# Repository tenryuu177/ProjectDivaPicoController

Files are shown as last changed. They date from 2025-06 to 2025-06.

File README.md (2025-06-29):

# Project Diva Controller

## Main features:
- Cheap (about 10€)
- Compact (fits 250x250 Print beds)
- 4 Main buttons
- Fake Slide pad using buttons
- Enter/Escape Keys

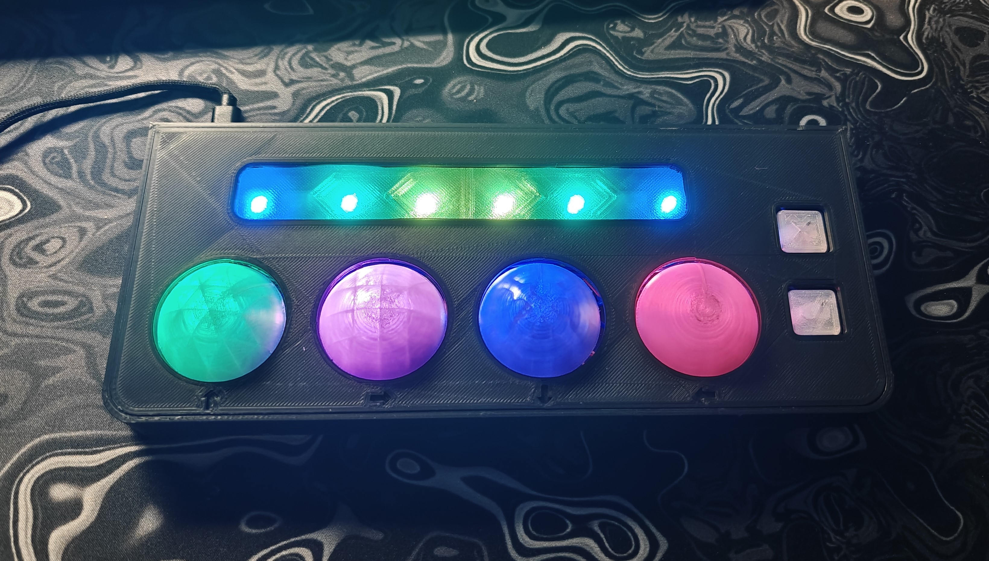
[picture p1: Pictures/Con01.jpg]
Con01


## What you need:
The links lead to AliExpress
- 1x [Raspberry Pi Pico (with USB-C)](https://www.aliexpress.com/item/1005008574488243.html?spm=a2g0o.order_list.order_list_main.5.2c061802aOrQjI)
- 8x [Kailh Choc switches](https://www.aliexpress.com/item/1005006626760418.html?spm=a2g0o.order_list.order_list_main.30.2c061802aOrQjI)
- 10x [WS2812B 5050SMD LEDs](https://www.aliexpress.com/item/4000750610574.html?spm=a2g0o.order_list.order_list_main.45.2c061802aOrQjI)
- super glue
- 3D Printer
- Clear Filament and any other color you might want
- Soldering Iron
- Wires
- Protoboard/Perfboard for easier wiring (optional but highly recommended)

# How to build:
Choose between the press fit and the M3 threaded version and print all parts.
The buttons don't require any (or only minimal) post-processing when printed with 0.1mm layers they are smooth enough as is.
Print the buttons with low infill so that they stay lightweight and more transparent. I choose to give them all different infill patterns similar to their symbol.

I used the following settings:

Triangle with 15% triangle infill, rotate 45° so that the pattern aligns.

Square with 10% grid infill pattern, rotate the part 45° so that the pattern aligns.

Circle with 10% concentric infill pattern.

Cross with 10% Cross pattern

'ChocStem' needs to be printed 4 times and they are going to be glued to the main buttons.

'ChocBody' needs to be printed 6 times and they are used for all the buttons.

'ChocBodyShort' needs to be printed 2 times and they are placed underneath the slidebar.

The ChocBody parts should have a pretty tight fit so that they can be pressed in place but still removed later if needed. Might need some sanding to get them in or you could just glue them in.

## Wiring
### Buttons
I choose the following GPIO Pins

Triangle/W GP16

Square/A GP17

Cross/S: GP18 

Circle/D: GP19 

Enter: GP20 

Escape: GP21 

Slide Left/Q: GP4 

Slide Right/E: GP5

However, you can wire these any way you want and then alter the assigned GPIO Pins starting from line 23 in the code.

### LEDs
The first 4 LEDs are Triangle, Square, Cross, and Circle in that order and light up along with button presses.

The last 6 LEDs should also be wired in series as in the picture, they have a RGB cycle and either side lights up respectively when pressed.

The Data In of the first LED has to be connected with GP0 after that, they are wired in series.
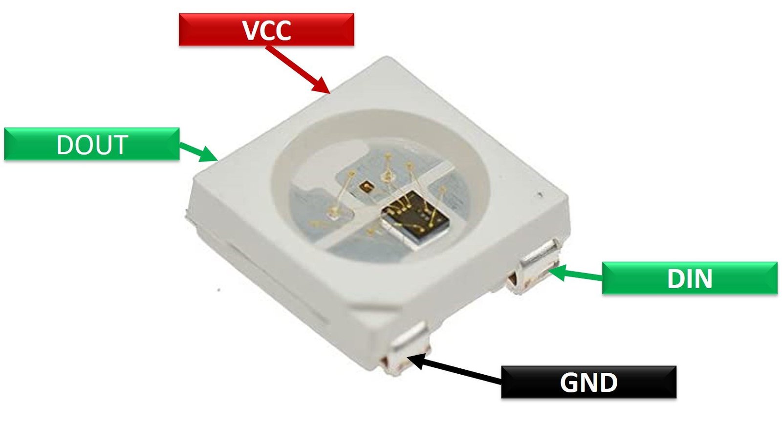
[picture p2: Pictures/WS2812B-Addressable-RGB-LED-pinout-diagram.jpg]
LED-Pinout

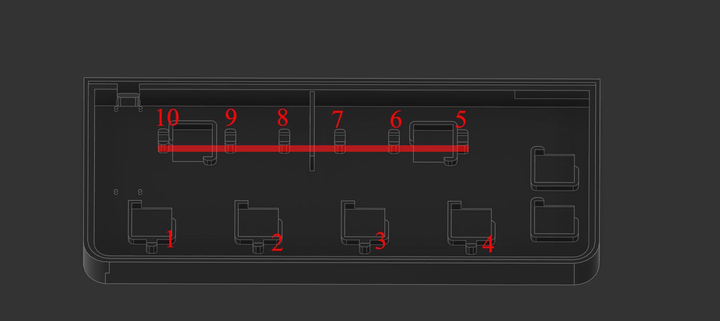
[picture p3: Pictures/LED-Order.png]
LED-Order


# Raspberry setup

First, flash your Raspberry with the latest Circuit Python version available: https://circuitpython.org/board/raspberry_pi_pico/

Then drop the content of the Raspberry folder onto your Raspberry.

The 'lib' folder and 'code.py' should be in root.

After disconnecting and reconnecting your Raspberry, the board should light up after a few seconds

# Disclaimer
The code was entirely written by Google Gemini.
I only changed some values for the LEDs

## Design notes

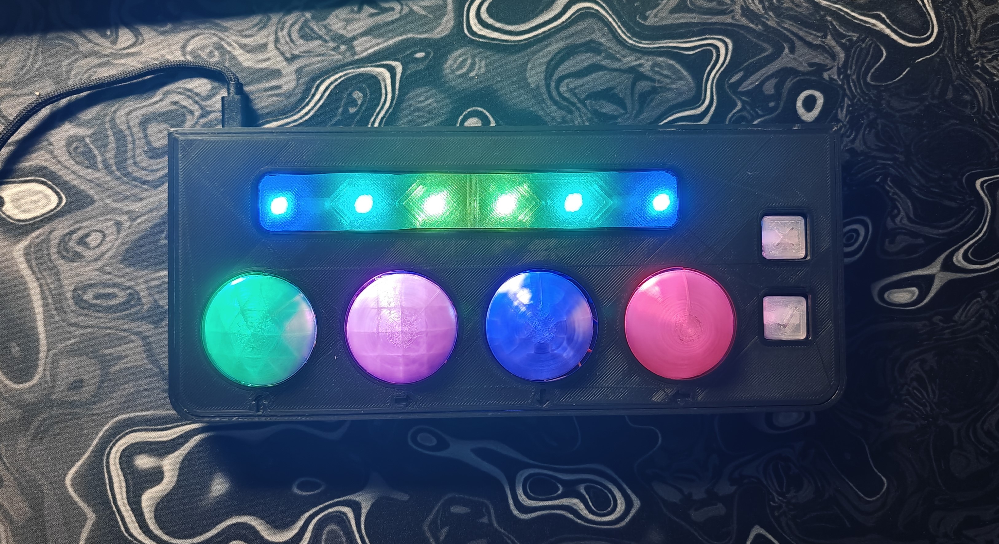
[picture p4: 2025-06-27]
Pictures/con02.jpg

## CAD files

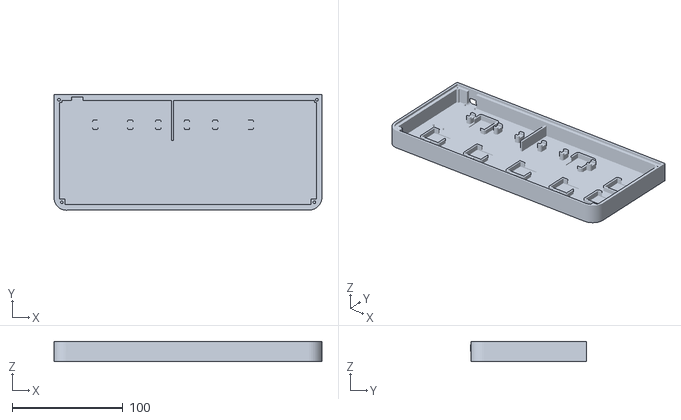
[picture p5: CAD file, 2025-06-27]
STL/01-1_BottomBodyM3Threaded.stl
242.2 x 104.4 x 18.2

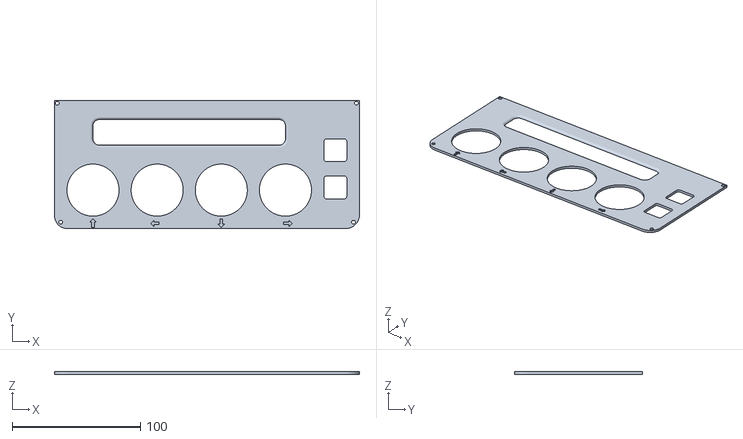
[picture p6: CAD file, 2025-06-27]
STL/02-1_Top coverM3Threaded.stl
237.7 x 99.9 x 2.00

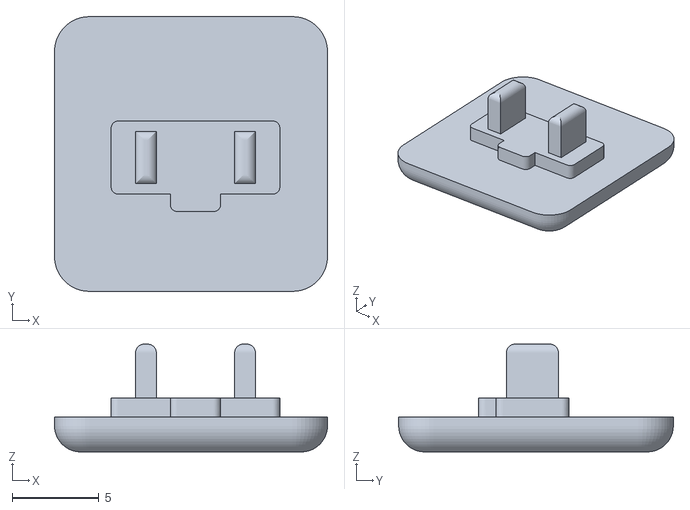
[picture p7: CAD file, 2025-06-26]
STL/12_Escape_Keycap.stl
15.7 x 15.8 x 6.20

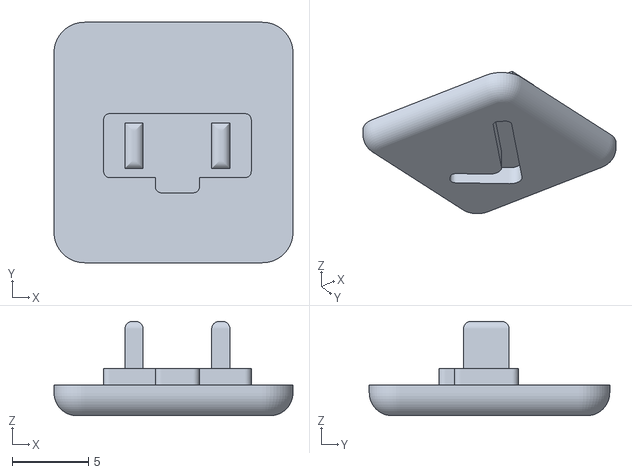
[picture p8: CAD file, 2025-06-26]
STL/11_Enter_Keycap.stl
15.7 x 15.8 x 6.20

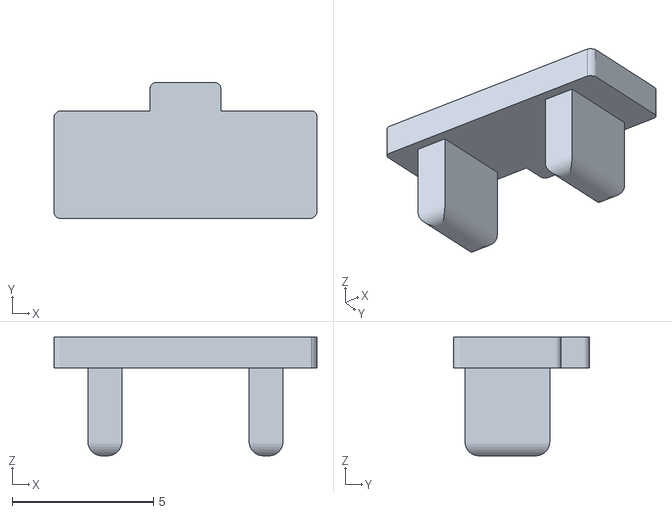
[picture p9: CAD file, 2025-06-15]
STL/03_ChocStem4X.stl.stl
9.30 x 4.80 x 4.20

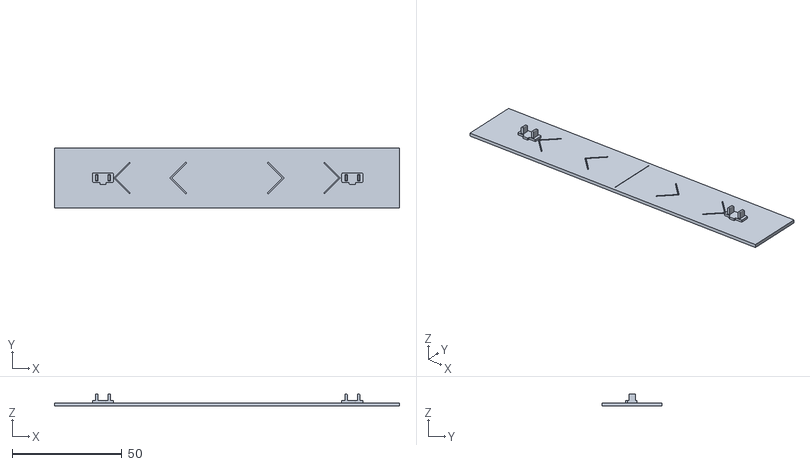
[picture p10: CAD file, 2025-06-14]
STL/10_Slidepad.stl
156.9 x 27.1 x 5.60

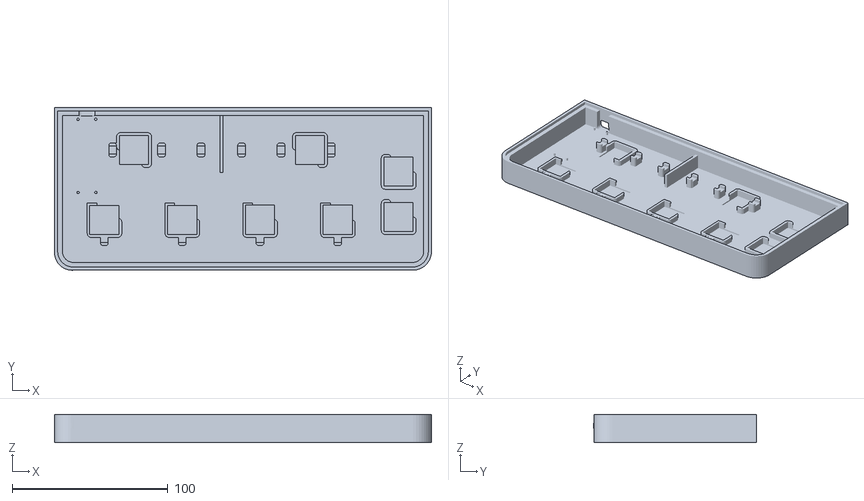
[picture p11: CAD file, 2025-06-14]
STL/01-2_BottomBodyPressFit.stl.stl
242.2 x 104.4 x 18.2

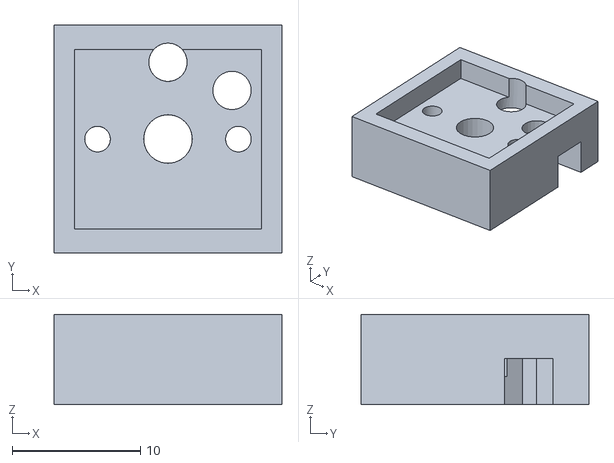
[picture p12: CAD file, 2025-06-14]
STL/08_ChocBody6X.stl
17.8 x 17.8 x 7.05

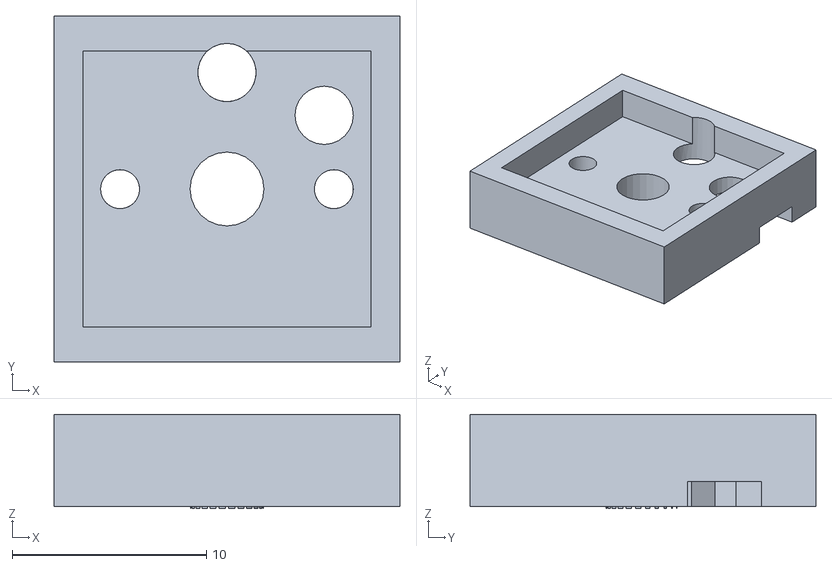
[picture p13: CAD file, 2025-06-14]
STL/09_ChocBodyShort2X.stl
17.8 x 17.8 x 4.85

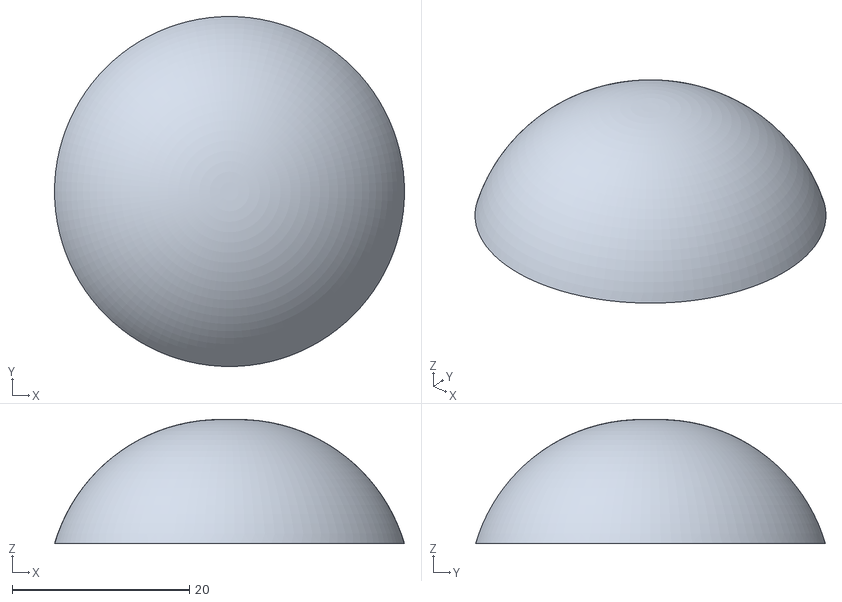
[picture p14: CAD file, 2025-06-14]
STL/04_Triangle.stl
39.5 x 39.5 x 14.0

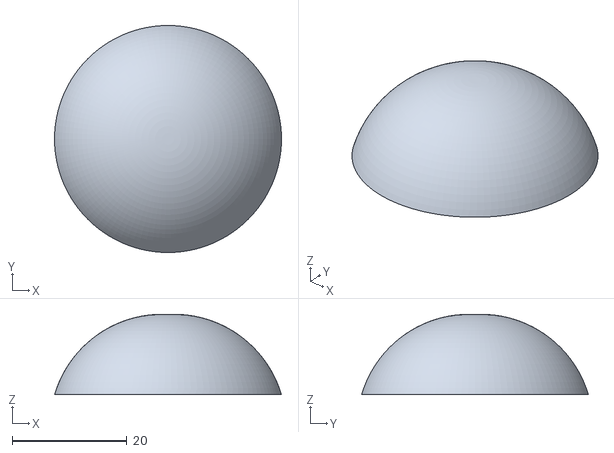
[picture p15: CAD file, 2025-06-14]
STL/06_Cross.stl
39.5 x 39.5 x 14.0

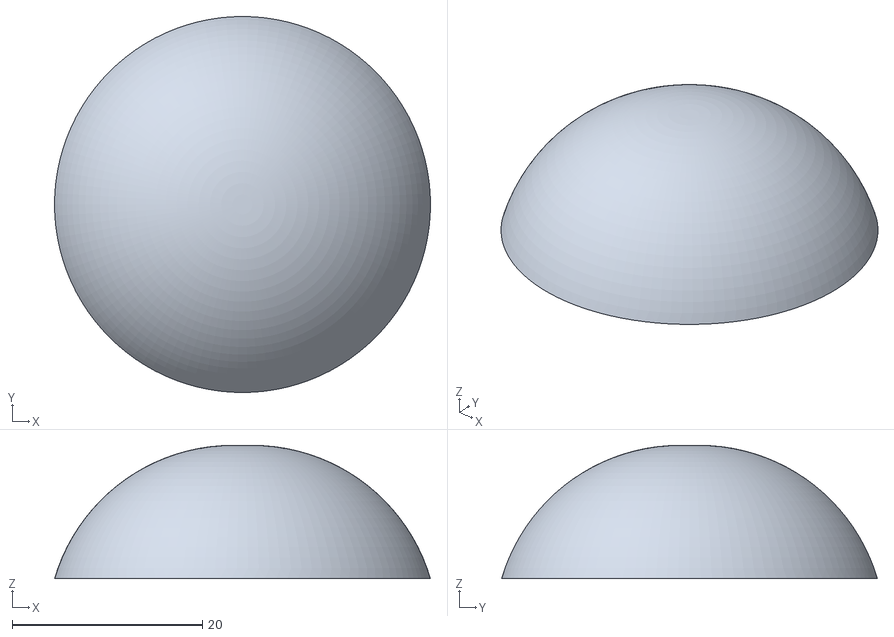
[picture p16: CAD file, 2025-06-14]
STL/07_Circle.stl
39.5 x 39.5 x 14.0

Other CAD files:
STL/02-2_Top coverPressfit.stl
STL/05_Square.stl

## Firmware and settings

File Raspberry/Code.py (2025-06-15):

import board
import digitalio
import usb_hid
import time
import neopixel
import math # Used for sine wave calculation for pulsing LEDs
from adafruit_hid.keyboard import Keyboard
from adafruit_hid.keycode import Keycode

# --- Configuration Section ---

# NeoPixel Setup:
# Connect the Data In (DI) pin of your WS2812B LED strip to GP0 on the Pico.
PIXEL_PIN = board.GP0
NUM_PIXELS = 10  # Total number of WS2812B LEDs in your strip/chain
BRIGHTNESS = 0.3 # Global brightness for all NeoPixels (0.0 to 1.0, 0.3 is a good starting point)

# Button Setup:
BUTTON_CONFIG = {
    board.GP16: Keycode.W,
    board.GP17: Keycode.A,
    board.GP18: Keycode.S,
    board.GP19: Keycode.D,
    board.GP4: Keycode.Q,
    board.GP5: Keycode.E,
    board.GP21: Keycode.ESCAPE,
    board.GP20: Keycode.ENTER,
}

# LED Base Colors (RGB tuples):
# These are the static colors when the LEDs are not actively pulsing or overridden.
COLOR_GREEN = (30, 255, 30)
COLOR_PINK = (255, 40, 255)
COLOR_BLUE = (60, 60, 255)
COLOR_RED = (255, 40, 40)
COLOR_YELLOW = (255, 255, 0)
COLOR_OFF = (0, 0, 0) # Represents an LED being off

# Pulsing Animation Configuration:
PULSE_DURATION = 0.5  # Time in seconds for one full pulse cycle (e.g., from dimmest to brightest and back)
PULSE_MAGNITUDE_FACTOR = 0.7 # How much the brightness varies during the pulse (0.0 = no change, 1.0 = dims significantly)

# Rainbow Flow Configuration:
# This value determines how quickly the color changes between adjacent LEDs in the rainbow.
# A larger value makes the colors more "cohesive" and appear to flow gradually,
# while a smaller value makes the color steps more distinct.
RAINBOW_INCREMENT_PER_LED = 40 # Adjusted for more distinct flow (e.g., 10-40)

# --- Initialization Section ---

# Initialize the HID Keyboard device for USB communication.
keyboard = Keyboard(usb_hid.devices)

# Initialize the NeoPixel strip.
# `auto_write=False` means we manually call `pixels.show()` to update the LEDs.
pixels = neopixel.NeoPixel(PIXEL_PIN, NUM_PIXELS, brightness=BRIGHTNESS, auto_write=False)

# Prepare button objects and their states.
# This dictionary will store the DigitalInOut object, keycode, and current pressed state for each button.
buttons = {}
for pin, keycode in BUTTON_CONFIG.items():
    button = digitalio.DigitalInOut(pin)
    button.direction = digitalio.Direction.INPUT
    button.pull = digitalio.Pull.UP  # Enable internal pull-up resistor for button input
    buttons[pin] = {"object": button, "keycode": keycode, "is_pressed": False}

# Store the `time.monotonic()` timestamp when a relevant button was last pressed.
# This helps in calculating the phase of the pulsing animation.
pulse_start_times = {
    Keycode.W: 0.0, # Initialize with 0.0 (or any non-zero value to indicate not pulsing)
    Keycode.A: 0.0,
    Keycode.S: 0.0,
    Keycode.D: 0.0,
}

# --- Helper Functions Section ---

def wheel(pos):
    """
    Generates a color from a rainbow wheel.
    Input `pos` is an integer from 0 to 255, representing a position in the color spectrum.
    Returns an RGB tuple (R, G, B).
    The colors transition smoothly from red -> green -> blue -> back to red.
    """
    if pos < 0 or pos > 255:
        return (0, 0, 0) # Return black if position is out of range
    if pos < 85:  # Red to Green
        return (255 - pos * 3, pos * 3, 0)
    if pos < 170: # Green to Blue
        pos -= 85
        return (0, 255 - pos * 3, pos * 3)
    # Blue to Red
    pos -= 170
    return (pos * 3, 0, 255 - pos * 3)

def apply_pulse(base_color, keycode, pulse_duration, pulse_magnitude_factor):
    """
    Adds a smooth pulsing effect to a given base color.
    The LED's brightness will smoothly cycle from `(1.0 - pulse_magnitude_factor)`
    of its original brightness up to `1.0` of its original brightness.
    """
    start_time = pulse_start_times[keycode]
    if start_time == 0.0:
        return base_color

    elapsed_time = time.monotonic() - start_time
    pulse_val = (math.sin(elapsed_time * 2 * math.pi / pulse_duration) + 1) / 2
    current_brightness_factor = (1.0 - pulse_magnitude_factor) + (pulse_val * pulse_magnitude_factor)
    adjusted_color = tuple(int(c * current_brightness_factor) for c in base_color)
    return adjusted_color

# --- Main Program Loop ---

rainbow_offset = 0  # Used to animate the rainbow spectrum for LEDs 5-10

while True:
    current_time = time.monotonic() # Get current time for precise pulsing calculations

    # --- 1. Process Button States ---
    for pin, button_data in buttons.items():
        button_obj = button_data["object"]
        keycode = button_data["keycode"]

        # Check if the button is currently pressed (pin reads LOW)
        # and if its state has changed from not pressed to pressed.
        if not button_obj.value and not button_data["is_pressed"]:
            buttons[pin]["is_pressed"] = True  # Update internal state
            keyboard.press(keycode)            # Send 'press' HID event to the computer
            
            # If this button is one of the ones that triggers an LED pulse,
            # record the current time as the start of its pulse.
            if keycode in pulse_start_times:
                pulse_start_times[keycode] = current_time

        # Check if the button is currently released (pin reads HIGH)
        # and if its state has changed from pressed to released.
        elif button_obj.value and button_data["is_pressed"]:
            buttons[pin]["is_pressed"] = False # Update internal state
            keyboard.release(keycode)          # Send 'release' HID event to the computer
            
            # If this button was pulsing, reset its pulse timer.
            # Setting it to 0.0 tells `apply_pulse` to stop pulsing.
            if keycode in pulse_start_times:
                pulse_start_times[keycode] = 0.0

    # --- 2. Update LED States ---

    # LED 1 (Index 0): Constant Green, Pulse when W is pressed.
    if buttons[board.GP16]["is_pressed"]: # Check if W key is currently held down
        pixels[0] = apply_pulse(COLOR_GREEN, Keycode.W, PULSE_DURATION, PULSE_MAGNITUDE_FACTOR)
    else:
        pixels[0] = COLOR_GREEN # Static green when W is not pressed

    # LED 2 (Index 1): Constant Pink, Pulse when A is pressed.
    if buttons[board.GP17]["is_pressed"]: # Check if A key is currently held down
        pixels[1] = apply_pulse(COLOR_PINK, Keycode.A, PULSE_DURATION, PULSE_MAGNITUDE_FACTOR)
    else:
        pixels[1] = COLOR_PINK

    # LED 3 (Index 2): Constant Blue, Pulse when S is pressed.
    if buttons[board.GP18]["is_pressed"]: # Check if S key is currently held down
        pixels[2] = apply_pulse(COLOR_BLUE, Keycode.S, PULSE_DURATION, PULSE_MAGNITUDE_FACTOR)
    else:
        pixels[2] = COLOR_BLUE

    # LED 4 (Index 3): Constant Red, Pulse when D is pressed.
    if buttons[board.GP19]["is_pressed"]: # Check if D key is currently held down
        pixels[3] = apply_pulse(COLOR_RED, Keycode.D, PULSE_DURATION, PULSE_MAGNITUDE_FACTOR)
    else:
        pixels[3] = COLOR_RED

    # Get states for Q and E buttons
    is_q_pressed = buttons[board.GP4]["is_pressed"]
    is_e_pressed = buttons[board.GP5]["is_pressed"]

    # LEDs 5-10 (Indices 4-9): Specific Yellow or Rainbow with directional flow
    for i in range(4, NUM_PIXELS): # Loop through LEDs from index 4 up to NUM_PIXELS-1 (LEDs 5 through 10)
        if i in [4, 5, 6] and is_e_pressed: # Check for LEDs 5, 6, 7 (indices 4, 5, 6) when E is pressed
            pixels[i] = COLOR_YELLOW
        elif i in [7, 8, 9] and is_q_pressed: # Check for LEDs 8, 9, 10 (indices 7, 8, 9) when Q is pressed
            pixels[i] = COLOR_YELLOW
        else:
            # Apply the rainbow cycling effect with directional flow
            if i in [4, 5, 6]:
                # LEDs 4, 5, 6: Flow from left to right (starting at LED 6 and ending at LED 4).
                # This means the color for LED 6 should be 'start', LED 5 'middle', LED 4 'end'.
                # To achieve this with `rainbow_offset` moving linearly, we invert the index.
                group_relative_index = 6 - i # 0 for i=6, 1 for i=5, 2 for i=4
                pixel_color_pos = (group_relative_index * RAINBOW_INCREMENT_PER_LED + rainbow_offset) % 256
                pixels[i] = wheel(pixel_color_pos)
            elif i in [7, 8, 9]:
                # LEDs 7, 8, 9: Flow from right to left (starting at LED 7 and ending at LED 9).
                # This means the color for LED 7 should be 'start', LED 8 'middle', LED 9 'end'.
                group_relative_index = i - 7 # 0 for i=7, 1 for i=8, 2 for i=9
                pixel_color_pos = (group_relative_index * RAINBOW_INCREMENT_PER_LED + rainbow_offset) % 256
                pixels[i] = wheel(pixel_color_pos)

    # Advance the rainbow animation for the next loop iteration.
    rainbow_offset = (rainbow_offset + 2) % 256 # Increased increment for faster flow

    pixels.show() # Send the updated color data to the NeoPixels. This makes the changes visible.

    time.sleep(0.01) # Small delay to prevent busy-waiting and allow other processes to run smoothly.

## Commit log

2025-06-13 Rename AV_Top cover.stl to 02_Top cover.stl
    [02_Top cover.stl]
2025-06-13 Rename 02_Top cover.stl to 02_Top coverPressfit.stl
    [02_Top coverPressfit.stl]
2025-06-13 Rename 02-1_Top coverM3Threaded.stl to 02-2_Top coverM3Threaded.stl
    [02-2_Top coverM3Threaded.stl]
2025-06-13 Rename 02_Top coverPressfit.stl to 02-1_Top coverPressfit.stl
    [02-1_Top coverPressfit.stl]
2025-06-13 Update and rename AV_ChocStem4X.stl to 03_ChocStem4X.stl
    [03_ChocStem4X.stl]
2025-06-14 Rename 02_Top cover.stl to 02-1_Top coverPressfit.stl
    [02-1_Top coverPressfit.stl]
2025-06-15 Update Code.py
    Changed LED colors and lighting effects
2025-06-27 Rename 02-1_Top coverPressfit.stl to 02-2_Top coverPressfit.stl
    [02-2_Top coverPressfit.stl]
2026-10-14 Fix tense in README.md instructions
    Corrected tense in instructions and GPIO pin section.
